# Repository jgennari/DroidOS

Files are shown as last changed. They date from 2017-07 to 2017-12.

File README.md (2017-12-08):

# DroidOS

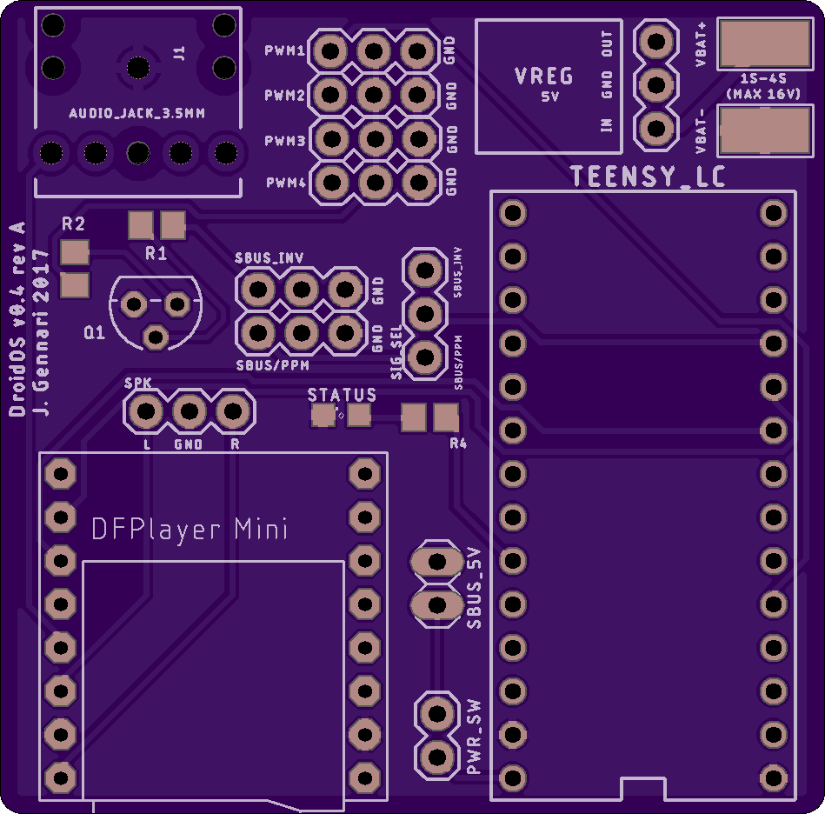
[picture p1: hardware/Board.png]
Board DroidOS Board


DroidOS is a Arduino based operating system for community built R2 units. It uses an SBUS-based RC receiver and an Arduino microcontroller to operate any number of extra functions on your droid.

## Bring your droid to life!

The DroidOS got us started in the right direction, however this project is just the starting point for us. It allows us to control lights and sound from the RC controller, but you can build anything on top of it. It's based on the Teensy LC development kit.

## Startup Sequence:  
The startup lives in the Arduino `setup` procedure. It follows this procedure:

* Initiate USB serial for debugging
* Initialize MP3 Player
* Initialize SBUS
* Confirm SBUS is communicating
* Check Mode Switch

During the setup, the status LED on the Teensy will be solid.

Any error will be annunciated via the status LED on the board. Short bursts indicate the failure mode, followed by no light for 1.5 seconds, repeated 3 times.

1. MP3 player initaliztion failed
2. Card online failed
3. Failed to count MP3 files
4. SBUS init failed, no serial control

Upon failure and notification the system will reset and re-enter the startup sequence.

## SBUS:
The SBUS library was sourced & slightly modified from [zendes](https://github.com/zendes/SBUS). We are using an FrSky X4R & X8R and are using inverted serial setup in Arduino. Once SBUS is connected and the main loop is running, any change to the SBUS first 6 channels will trigger a brief flash of the Teensy status LED.

## Questions/suggestions
If you have any questions or suggestions please feel free to reach out via GitHub or submit and issue.

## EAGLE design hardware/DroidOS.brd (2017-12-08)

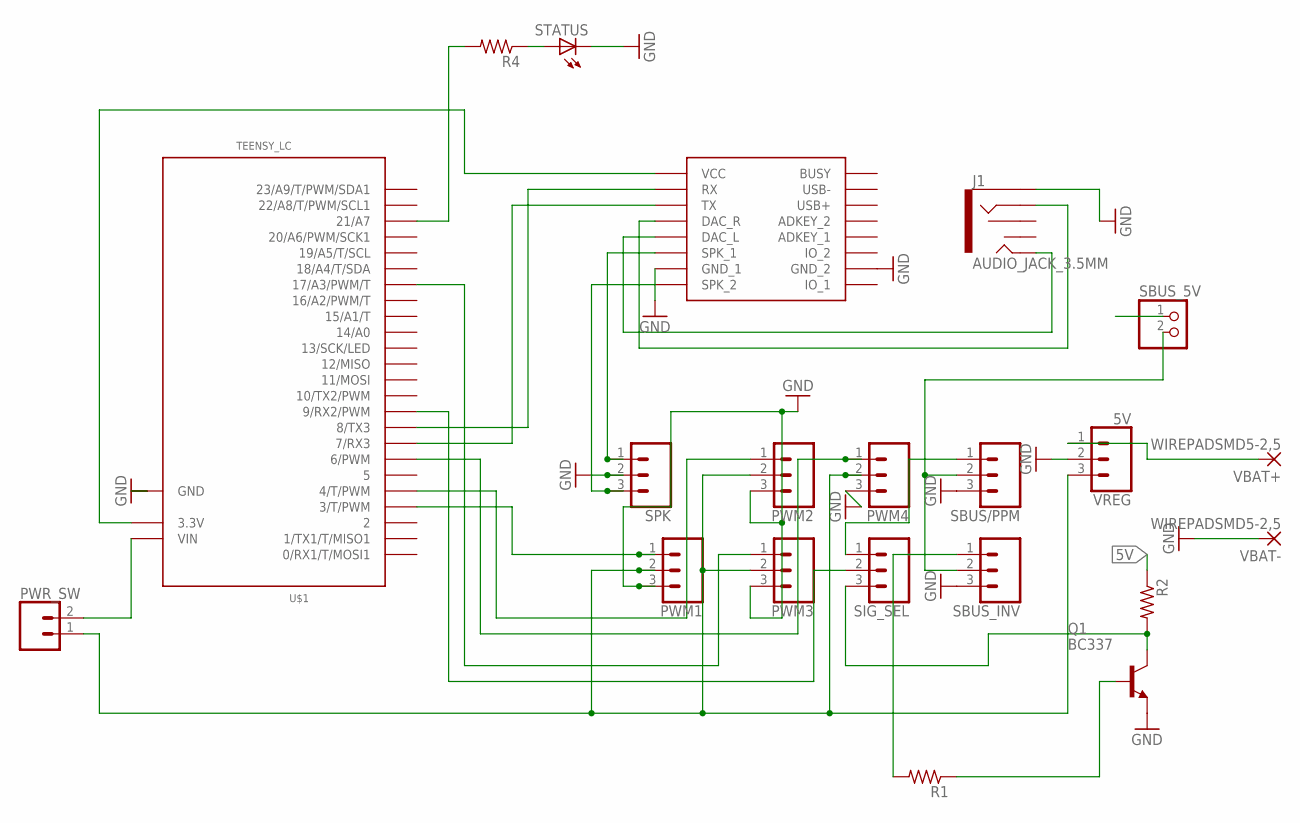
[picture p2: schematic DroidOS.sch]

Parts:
J1: AUDIO_JACK_3.5MM; AUDIO-JACK-KIT
PWM1, PWM2, PWM3, PWM4: CONN_03; 1X03
PWR_SW: CONN_02; 1X02
Q1: BC337; TO92
R1, R2, R4: R-US_R0805; R0805
SBUS/PPM: CONN_03; 1X03
SBUS_5V: PINHD-1X2; 1X02
SBUS_INV: CONN_03; 1X03
SIG_SEL: CONN_03; 1X03
SPK: CONN_03; 1X03
STATUS: LEDSML0805; SML0805
U$1: TEENSY_LC; TEENSY_3.0-3.2&LC_DIL
U$2: DFPLAYER
VBAT+: WIREPADSMD5-2,5; 5-2,5
VBAT-: WIREPADSMD5-2,5; 5-2,5
VREG: 5V; 1X03

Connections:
3V+: U$1.3.3V, U$2.VCC
5V: PWM1.2, PWM2.2, PWM3.2, PWM4.2, PWR_SW.1, R2.1, SBUS_5V.1, VREG.3
AUD_RX: U$1.8 (8/TX3), U$2.RX
AUD_TX: U$1.7 (7/RX3), U$2.TX
CTRL_SIG: SIG_SEL.2, U$1.9 (9/RX2/PWM)
DAC_L: J1.TIP, U$2.DAC_L
DAC_R: J1.RING, U$2.DAC_R
GND: J1.SLEEVE, PWM1.3, PWM2.3, PWM3.3, PWM4.3, Q1.1 (E), SBUS/PPM.3, SBUS_INV.3, SPK.2, STATUS.C, U$1.AGND (GND), U$1.GND, U$2.GND_1, U$2.GND_2, VBAT-.1, VREG.2
unnamed: PWR_SW.2, U$1.VIN
unnamed: R4.1, STATUS.A
unnamed: SBUS/PPM.2, SBUS_5V.2, SBUS_INV.2
unnamed: Q1.2 (B), R1.1
PWM1_SIG: PWM1.1, U$1.3 (3/T/PWM)
PWM2_SIG: PWM2.1, U$1.4 (4/T/PWM)
PWM3_SIG: PWM3.1, U$1.17/A3 (17/A3/PWM/T)
PWM4_SIG: PWM4.1, U$1.6 (6/PWM)
SBUS_INV_IN: R1.2, SBUS_INV.1
SBUS_INV_OUT: Q1.3 (C), R2.2, SIG_SEL.3
SBUS_OUT: SBUS/PPM.1, SIG_SEL.1
SPK_L: SPK.1, U$2.SPK1 (SPK_1)
SPK_R: SPK.3, U$2.SPK2 (SPK_2)
STATUS_LED: R4.2, U$1.21/A7
VBAT: VBAT+.1, VREG.1

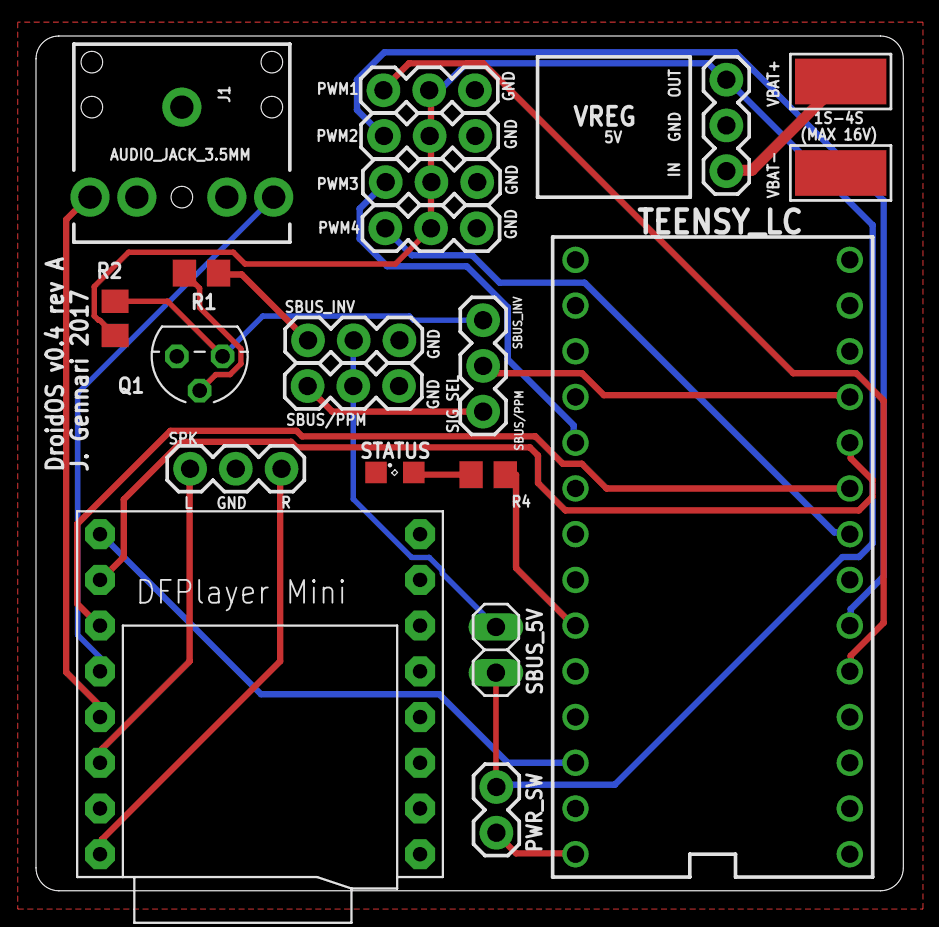
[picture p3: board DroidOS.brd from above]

Board: 2 copper layers, 48.2 x 47.5 mm, 21 parts (0 on the bottom side), 23 nets.

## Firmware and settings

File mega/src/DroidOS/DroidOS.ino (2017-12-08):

#include <Servo.h>

// DroidOS v1.18 by Joey Gennari
// This is the operating system that powers our R2 unit. It includes an MP3
// player from DFPlayer and an SBUS receiver to initiate responses based on
// the RC controller. This sketch is designed for the Teency LC to take
// use of 3 serial buses.

#include "DFRobotDFPlayerMini.h"         // MP3 Player Library
#include "SBUS.h"                        // SBUS Library
#include "Queue.h"                       // Queue for log management

DFRobotDFPlayerMini mp3player;           // Declare MP3 player_active
SBUS x4r(Serial2);                       // Declare RC recv, assign to S2
Queue<String> logs = Queue<String>(20);  // Queue of logs

// System and cloud variables
String dosversion = "v1.18";             // DroidOS version
String readlog;                          // Last debug message for cloud
String systemstatus;                     // System status for cloud
String systemstatus_last;                // Last system status displayed
int systemstatus_time;                   // Time (in millis) since last
const int reset_timeout = 5000;          // Start reset after value, in millis
const int sound_threshold = 35;          // Percent before activating sound
bool is_connected = false;               // Cloud connection status
bool show_activity = false;              // Show the loops in the consoleupdate
bool show_changes = true;                // Show RC changes in console
double battcharge;                       // Charge % of internal battery
int log_length;                          // Number of log entries unread
int freememory;                          // Free memory available
int systemloop;                          // Time (in millis) since sys update
const int board_led = 13;                // LED on the board
const int status_led_duration = 100;     // Length of time to flash the LED
const int status_led_off = 4000;         // Time of off period
int status_led_last = 0;                 // Last flash time
int status_led_state = LOW;              // Current state
const int mp3_timer_interval = 10;       // Time in between MP3 polls
int mp3_timer = 0;                       // Last MP3 poll
const int sbus_timer_interval = 25;      // Time in between SBUS polls
int sbus_timer = 0;                      // Last SBUS poll

// Keep track of the status of the MP3 player, including the last song played
// and the state of the player to avoid errors
bool player_active = false;              // Is the MP3 player initialized
bool player_card = false;                // Is the card mounted yet
int song_index[] = { 0, 0 };             // The index of the happy/sad songs
int song_count[] = { 0, 0 };             // The count of the happy/sad songs
bool is_playing = false;                 // Debounce playing efforts
int is_playing_last;                     // Time (in millis) since last playing
int last_finished;                       // Only reset for each play
int is_playing_timeout = 800;            // Debounce timeout
int last_volume;                         // Last volume

// SBUS channel positions, refreshed in the sbus_update proc, 1-based index
int channels[17];                         // 16ch and their -100 to 100 value
int sbus_inactive_value = -100;           // Value of inactivated SBUS channels
int sbus_inactive_value_2 = 0 ;           // Value of inactivated SBUS channels
bool use_sbus = true;                     // If no SBUS connected, use serial

// SBUS channel mappings
const int gimbal_leftdrive = 1;
const int gimbal_rightdrive = 3;
const int gimbal_sound = 4;
const int gimbal_head = 2;
const int rotary_volume = 5;
const int switch_mode = 6;

void resetFunc() {
  SCB_AIRCR = 0x05FA0004;
  delay(2000);  
}

void setup() {
  // Open debugging serial port
  Serial.begin(115200);

  pinMode(board_led, OUTPUT);     
  digitalWrite(board_led, HIGH);
  
  Serial.print("DroidOS " + dosversion + " starting up ");
  for (int i=0; i <= 3; i++){
    Serial.print(".");
    delay(1000);
  }
  Serial.println(".");
   
  // Connect to the MP3 player
  startplayer();
  if (!player_active {
    log("MP3 player initaliztion failed, resetting system.");
    flash_error(1));
    resetFunc();
  }
  else {
    log("Waiting for card online.");
    int player_card_start = millis();
    while (!player_card) {
      mp3_update();
      if (millis() - player_card_start > 20000) {
        log("Card online failed, resetting system.");
        flash_error(2);
        resetFunc();
      }
    }
  }

  // Count files in Happy & Sad
  int tries = 0;
  while (tries < 5) {
    song_count[0] = mp3player.readFileCountsInFolder(1);
    song_count[1] = mp3player.readFileCountsInFolder(2);
    log("Found " + String(song_count[0]) + " in happy and " + String(song_count[1]) + " in sad.");

    // For some reason the file count proc sometimes returns -1, if it does,
    // try again for 3 times. If it fails, reset the system
    if ((song_count[0] < 1 || song_count[1] < 1) && tries == 4) {
      log("File counts failed, resetting system.");
      flash_error(3);
      resetplayer();
      resetFunc();
    } else if (song_count[0] < 1 || song_count[1] < 1) {
      tries++;
    } else {
      break;
    }
  }
  
  // Initialize SBUS
  x4r.begin(false);

  // Wait for SBUS to init   
  for (int i=0; i <= 50; i++){
    sbus_update();
    delay(25);
  }

  // If SBUS initaliztion failed, log, wait and reset
  if ((channels[gimbal_leftdrive] == sbus_inactive_value
    && channels[gimbal_rightdrive] == sbus_inactive_value
    && channels[gimbal_head] == sbus_inactive_value
    && channels[gimbal_sound] == sbus_inactive_value) ||
    (channels[gimbal_leftdrive] == sbus_inactive_value_2
    && channels[gimbal_rightdrive] == sbus_inactive_value_2
    && channels[gimbal_head] == sbus_inactive_value_2
    && channels[gimbal_sound] == sbus_inactive_value_2)) {
      // Check to see if someone is on the serial terminal
      int serialcontrol_start = millis();
      Serial.print("Press any key to use serial control ");

      while(millis() - serialcontrol_start < 3000) {
        if (Serial.available() > 0) {
          Serial.println("");
          log("Using serial control.");

          // Reset all controls to 0
          controls_reset();

          // Allow the droid to be controlled by serial messages
          use_sbus = false;
          break;
        }
        Serial.print(".");

        // Don't flood the console with .
        delay(500);
      }

      // No one is on the terminal and the SBUS channels are empty
      if (use_sbus) {
        Serial.println("");
        log("SBUS initaliztion failed, resetting system.");
        flash_error(4);
        resetFunc();
      }
  }

  // Turn status light off
  digitalWrite(board_led, LOW);
  status_led_last = millis();
  log("Setup complete.");
}

void flash_error(int times) {
  digitalWrite(board_led, LOW);  
  delay(500);
  for (int ix=0; ix <= 2; ix++) {   
    for (int i=0; i <= times-1; i++) {
      digitalWrite(board_led, HIGH);  
      delay(200);
      digitalWrite(board_led, LOW);  
      delay(200);
    } 
    delay(1500);
  }  
}

void loop() {
  if (show_activity)
    Serial.print(".");

  if (status_led_state == HIGH && millis() - status_led_last >= status_led_duration) {
    status_led_last = millis();
    status_led_state = LOW;
  }
  else if (status_led_state == LOW && millis() - status_led_last >= status_led_off) {
    status_led_last = millis();
    status_led_state = HIGH;    
  }
  digitalWrite(board_led, status_led_state);
  
  // Write a cloud variable with all the debug info
  update_status();

  if (millis() - mp3_timer > mp3_timer_interval) {
    mp3_update();  
    mp3_timer = millis();
  }
  
  if (millis() - sbus_timer > sbus_timer_interval) {
    sbus_update();
    sbus_timer = millis();
  }
  
  // Only update system variables every 5 sec
  if (millis() - systemloop > 500) {
    systemloop = millis();
  }

  // Initiate local reset
  if (channels[gimbal_sound] < -50 && channels[gimbal_head] > 50) {
    delay(reset_timeout);
    if (channels[gimbal_sound] < -50 && channels[gimbal_head] > 50)
      systemreset("Local");
  }

  // If not playing and ch4 pushed right, play happy
  if (channels[gimbal_sound] > sound_threshold)
    play_happy();

  // If not playing and ch4 pushed right, play happy
  if (channels[gimbal_sound] < -sound_threshold)
    play_sad();

  // Check the volume, translate RC and change if necessary
  int current_volume = translate_volume();
  if (last_volume != current_volume) {
    last_volume = current_volume;
    mp3player.volume(current_volume);
  }

  if (is_playing && millis() - is_playing_last > is_playing_timeout) {
    log("Force is_playing false.");
    is_playing = false;
  }
}

void mp3_update() {
  if (show_activity)
    Serial.print("m");

  // Log changes to the MP3 player state
  if (player_active && (!player_card || mp3player.available()))
    decode_mp3status(mp3player.readType(), mp3player.read());
}

int systemreset(String extra) {
  if (extra == "Local") {
    log("Local reset initiated.");
    play_notification(9);
  } else {
    log("Cloud reset initiated.");
    play_notification(8);
  }

  delay(3000);
  resetFunc();
  return 1;
}

void log(String message) {
  if (message.length() > 0) {
    Serial.println(message);
    logs.push(message);
    log_length = logs.count();
  }
}

int clearlog(String extra) {
  logs.clear();
  log_length = logs.count();
  return logs.count();
}

int advancelog(String extra) {
  if (logs.count() > 0)
    readlog = logs.pop();
  else
    readlog = "End of log.";

  log_length = logs.count();
  return logs.count();
}

void startplayer() {
  log("Starting DFPlayer serial.");
  Serial3.begin(9600);

  // Delay to make sure serial connects
  delay(1500);

  log("Connecting DFPlayer serial.");
  if (!mp3player.begin(Serial3))  {
    player_active = false;
    log("DFPlayer Mini failed.");
  }
  else  {
    log("DFPlayer Mini online.");
    player_active = true;
    mp3player.volume(10);
  }
}

void resetplayer() {
  log("Resetting player.");
  player_active = false;
  player_card = false;
  mp3player.reset();
  delay(1000);
  log("Player reset.");
  player_active = true;
}

void update_status() {
  systemstatus = "L:" +
    String(channels[gimbal_leftdrive]) +
    "R:" +
    String(channels[gimbal_rightdrive]) +
    "S:" +
    String(channels[gimbal_sound]) +
    "H:" +
    String(channels[gimbal_head]) +
    "V:" +
    String(channels[rotary_volume]) +
    "M:" +
    String(channels[switch_mode]);

  if ((systemstatus_last != systemstatus)) {
    if (show_changes) {
      systemstatus_time = millis();
      systemstatus_last = systemstatus;
      Serial.println(systemstatus);
    }    
    status_led_last = millis();
    status_led_state = HIGH;
    digitalWrite(board_led, status_led_state);
  }
}

int translate_volume() {
  int normalized = channels[rotary_volume]+80;
  float equalized = normalized/160.0f;
  float spread = equalized*30;
  int newvolume = (int)spread;

  if (newvolume < 0) {
    newvolume = 0;
  }
  else if (newvolume > 30) {
    newvolume = 30;
  }

  return newvolume;
}

void sbus_update() {
  if (show_activity)
    Serial.print("s");

  if (use_sbus) {
    x4r.process();
    channels[gimbal_leftdrive] = x4r.getNormalizedChannel(gimbal_leftdrive);
    channels[gimbal_rightdrive] = x4r.getNormalizedChannel(gimbal_rightdrive);
    channels[gimbal_head] = x4r.getNormalizedChannel(gimbal_head);
    channels[gimbal_sound] = x4r.getNormalizedChannel(gimbal_sound);
    channels[rotary_volume] = x4r.getNormalizedChannel(rotary_volume);
    channels[switch_mode] = x4r.getNormalizedChannel(switch_mode);
  } else {
    if(Serial.available() > 0)
    {
        int ch = Serial.readStringUntil(':').toInt();
        int val = Serial.parseInt();
        manual_control(ch, val);
    }
  }
}

int remote_ctrl(String command) {
  int split = command.indexOf(":");
  int ch = command.substring(0, split).toInt();
  int val = command.substring(split+1).toInt();
  manual_control(ch, val);
  return 1;
}

void manual_control(int ch, int val) {
  systemstatus_time = millis();
  if (ch == 99) {
    resetplayer();
  }
  else if (ch == 98) {
    if (val == 1)
      play_happy();
    else
      play_sad();
  }
  else if (ch == 97) {
    play_notification(val);
  }
  else if (ch == 96) {
    log("Resetting system ...");
    delay(2000);
    resetFunc();
  }
  else if (ch == 95) {
    log("Entering DFU ...");
    delay(2000);
    resetFunc();
  }
  else if (ch > 0) {
    channels[ch] = val;
  }
}

void controls_reset() {
  channels[gimbal_leftdrive] = 0;
  channels[gimbal_rightdrive] = 0;
  channels[gimbal_head] = 0;
  channels[gimbal_sound] = 0;
  channels[rotary_volume] = 0;
  channels[switch_mode] = -80;
}

void play_happy() {
  if (is_playing)
    return;

  is_playing = true;
  is_playing_last = millis();

  if (song_index[0] < song_count[0])
      song_index[0] = song_index[0] + 1;
  else
      song_index[0] = 1;

  log("Playing happy clip: " + String(song_index[0]));
  mp3player.playFolder(1, song_index[0]);
}

void play_sad() {
  if (is_playing)
    return;

  is_playing = true;
  is_playing_last = millis();
  if (song_index[1] < song_count[1])
      song_index[1] = song_index[1] + 1;
  else
      song_index[1] = 1;

  log("Playing sad clip: " + String(song_index[1]));
  mp3player.playFolder(2, song_index[1]);
}

void play_notification(int notification) {
  if (player_active && player_card) {
    log("Playing notification " + String(notification) + ".");
    mp3player.playFolder(3, notification);
  }
}

void decode_mp3status(uint8_t type, int value) {
  String mp3error;

  switch (type) {
    case TimeOut:
      log("Time Out!");
      break;
    case WrongStack:
      log("Stack Wrong!");
      break;
    case DFPlayerCardInserted:
      log("Card Inserted!");
      break;
    case DFPlayerCardRemoved:
      log("Card Removed!");
      player_card = false;
      break;
    case DFPlayerCardOnline:
      log("Card Online!");
      player_card = true;
      break;
    case DFPlayerPlayFinished:
      if (value != last_finished) {
        last_finished = value;
        log("Play " + String(value) + " Finished!");
        is_playing = false;
      }
      break;
    case DFPlayerError:
      switch (value) {
        case Busy:
          mp3error = "Card not found";
          break;
        case Sleeping:
          mp3error = "Sleeping";
          break;
        case SerialWrongStack:
          mp3error = "Get Wrong Stack";
          break;
        case CheckSumNotMatch:
          mp3error = "Checksum Not Match";
          break;
        case FileIndexOut:
          mp3error = "File Index Out of Bound";
          break;
        case FileMismatch:
          mp3error = "Cannot Find File";
          break;
        case Advertise:
          mp3error = "In Advertise";
          break;
        default:
          break;
      }

      log("DFPlayerError: " + mp3error);
      break;
    default:
      break;
  }
}

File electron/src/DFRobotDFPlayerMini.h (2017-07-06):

/*!
 * @file DFRobotDFPlayerMini.h
 * @brief DFPlayer - An Arduino Mini MP3 Player From DFRobot
 * @n Header file for DFRobot's DFPlayer
 *
 * @copyright	[DFRobot]( http://www.dfrobot.com ), 2016
 * @copyright	GNU Lesser General Public License
 *
 * @author [Angelo](Angelo.qiao@dfrobot.com)
 * @version  V1.0
 * @date  2016-12-07
 */

#include "Arduino.h"

#ifndef DFRobotDFPlayerMini_cpp
    #define DFRobotDFPlayerMini_cpp


#define DFPLAYER_EQ_NORMAL 0
#define DFPLAYER_EQ_POP 1
#define DFPLAYER_EQ_ROCK 2
#define DFPLAYER_EQ_JAZZ 3
#define DFPLAYER_EQ_CLASSIC 4
#define DFPLAYER_EQ_BASS 5

#define DFPLAYER_DEVICE_U_DISK 1
#define DFPLAYER_DEVICE_SD 2
#define DFPLAYER_DEVICE_AUX 3
#define DFPLAYER_DEVICE_SLEEP 4
#define DFPLAYER_DEVICE_FLASH 5

#define DFPLAYER_RECEIVED_LENGTH 10
#define DFPLAYER_SEND_LENGTH 10

//#define _DEBUG

#define TimeOut 0
#define WrongStack 1
#define DFPlayerCardInserted 2
#define DFPlayerCardRemoved 3
#define DFPlayerCardOnline 4
#define DFPlayerPlayFinished 5
#define DFPlayerError 6

#define Busy 1
#define Sleeping 2
#define SerialWrongStack 3
#define CheckSumNotMatch 4
#define FileIndexOut 5
#define FileMismatch 6
#define Advertise 7

#define Stack_Header 0
#define Stack_Version 1
#define Stack_Length 2
#define Stack_Command 3
#define Stack_ACK 4
#define Stack_Parameter 5
#define Stack_CheckSum 7
#define Stack_End 9

class DFRobotDFPlayerMini {
  Stream* _serial;

  unsigned long _timeOutTimer;
  unsigned long _timeOutDuration = 500;

  uint8_t _received[DFPLAYER_RECEIVED_LENGTH];
  uint8_t _sending[DFPLAYER_SEND_LENGTH] = {0x7E, 0xFF, 06, 00, 01, 00, 00, 00, 00, 0xEF};

  uint8_t _receivedIndex=0;

  void sendStack();
  void sendStack(uint8_t command);
  void sendStack(uint8_t command, uint16_t argument);
  void sendStack(uint8_t command, uint8_t argumentHigh, uint8_t argumentLow);

  void enableACK();
  void disableACK();

  void uint16ToArray(uint16_t value,uint8_t *array);

  uint16_t arrayToUint16(uint8_t *array);

  uint16_t calculateCheckSum(uint8_t *buffer);



  void parseStack();
  bool validateStack();

  uint8_t device = DFPLAYER_DEVICE_SD;

  public:

  uint8_t _handleType;
  uint8_t _handleCommand;
  uint16_t _handleParameter;
  bool _isAvailable = false;
  bool _isSending = false;

  bool handleMessage(uint8_t type, uint16_t parameter = 0);
  bool handleError(uint8_t type, uint16_t parameter = 0);

  uint8_t readCommand();

  bool begin(Stream& stream, bool isACK = true);

  bool waitAvailable();

  bool available();

  uint8_t readType();

  uint16_t read();

  void setTimeOut(unsigned long timeOutDuration);

  void next();

  void previous();

  void play(int fileNumber=1);

  void volumeUp();

  void volumeDown();

  void volume(uint8_t volume);

  void EQ(uint8_t eq);

  void loop(int fileNumber);

  void outputDevice(uint8_t device);

  void sleep();

  void reset();

  void start();

  void pause();

  void playFolder(uint8_t folderNumber, uint8_t fileNumber);

  void outputSetting(bool enable, uint8_t gain);

  void enableLoopAll();

  void disableLoopAll();

  void playMp3Folder(int fileNumber);

  void advertise(int fileNumber);

  void playLargeFolder(uint8_t folderNumber, uint16_t fileNumber);

  void stopAdvertise();

  void stop();

  void loopFolder(int folderNumber);

  void randomAll();

  void enableLoop();

  void disableLoop();

  void enableDAC();

  void disableDAC();

  int readState();

  int readVolume();

  uint8_t readEQ();

  int readFileCounts(uint8_t device);

  int readCurrentFileNumber(uint8_t device);

  int readFileCountsInFolder(int folderNumber);

  int readFileCounts();

  int readFolderCounts();

  int readCurrentFileNumber();

};

#endif

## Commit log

2017-07-05 Tweaked MP3 player failure handling
    [DroidOS.ino]
2017-07-06 Refactored timer code, stabilized audio
    [DFRobotDFPlayerMini.h, DroidOS.ino]
2017-07-07 Lots of fixes, remote control, remote logging
    [DroidOS.ino]
2017-10-24 Added hardware files
    [DroidOS.fzz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]
2017-10-26 Added Eagle
    [DroidOS.brd, DroidOS.sch]
2017-10-26 Changed layout
    [DroidOS.brd, DroidOS.sch]
2017-11-17 Changed to Serial3 for Teensy LC
2017-11-18 Changes for Teensy
2017-12-07 Updated ino for Teensy/SBUS
2017-12-07 Added SBUS power out
    [DroidOS.brd, DroidOS.sch]
2017-12-08 Updated code to show error blinks on boot
    [DroidOS.ino]
2017-12-08 Added board to readme

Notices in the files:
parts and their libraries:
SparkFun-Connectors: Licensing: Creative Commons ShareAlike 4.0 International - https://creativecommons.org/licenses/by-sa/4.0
